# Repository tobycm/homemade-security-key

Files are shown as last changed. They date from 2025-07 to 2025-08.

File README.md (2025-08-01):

# homemade-security-key

DIY a security key! powered by a rp2350 for a pretty good security :D

with a nice 3d printed case and it is also easy to print, this key is hella nice for only 6$ each 🔥

the pcb is still well made tho, considerate thoughts have been put into the usb routing, and power delivery too!

## 3D Render

### PCB

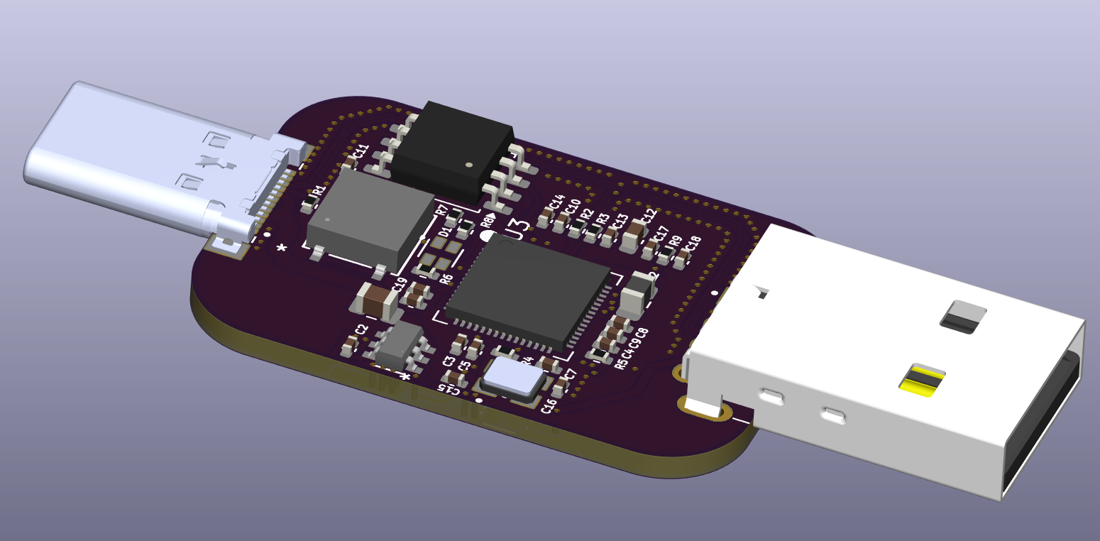
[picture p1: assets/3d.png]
3d render


### Case

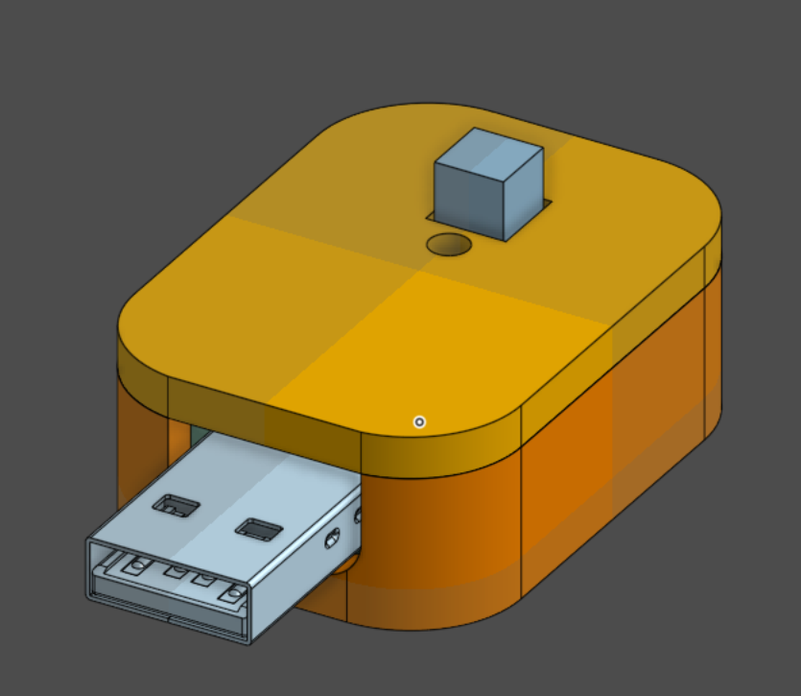
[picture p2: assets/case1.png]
case1


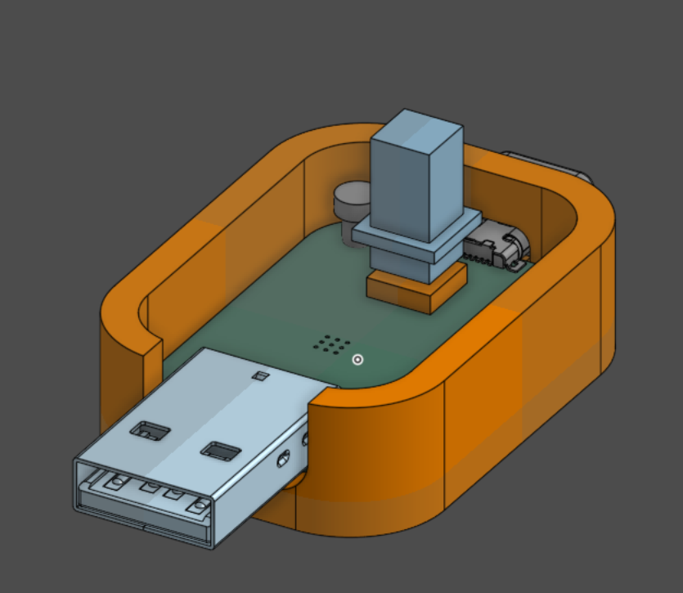
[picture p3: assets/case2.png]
case2


| Type | Qty | Value |
| :--- | :-- | :--- |
| Capacitor | 1 | 10u |
| Capacitor | 10 | 100n |
| Capacitor | 1 | 1u |
| Capacitor | 1 | 22u |
| Capacitor | 4 | 4.7u |
| Capacitor | 2 | 18p |
| LED | 1 | B38G3RGB-10D0003H2U1930 |
| Connector | 1 | UP20-C-F-G-FL-1-P12-TR |
| Connector | 1 | UP2-AH-1-TH |
| Inductor | 1 | 4.7u |
| Inductor | 1 | AOTA-B201610S3R3-101-T |
| Resistor | 1 | 5.1k |
| Resistor | 2 | 27 |
| Resistor | 1 | 1k |
| Resistor | 1 | 10k |
| Resistor | 1 | 147 |
| Resistor | 3 | 33 |
| Button | 1 | PTS526SM15SMTR2 LFS |
| Buck regulator | 1 | AP63203WU-7 |
| Flash | 1 | W25Q16JVSS |
| MCU | 1 | RP2350A-QFN60 |
| Crystal | 1 | ABM8-272-T3 |
| PCB | 1 | |
| Stencil | 1 | |
| Solder paste | 1 | I already have |

---
**Total cost:** $64.78 USD

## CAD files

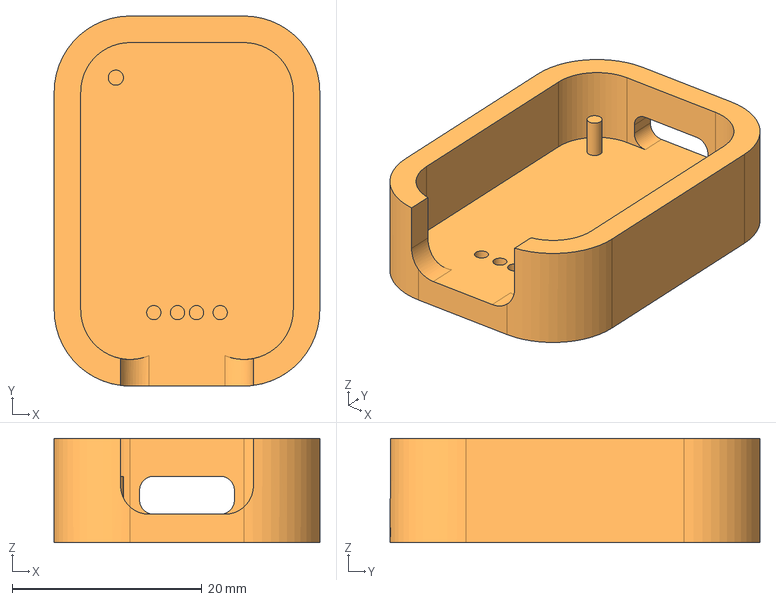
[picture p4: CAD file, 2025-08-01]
3d/main case.step
28.0 x 39.0 x 11.0 mm

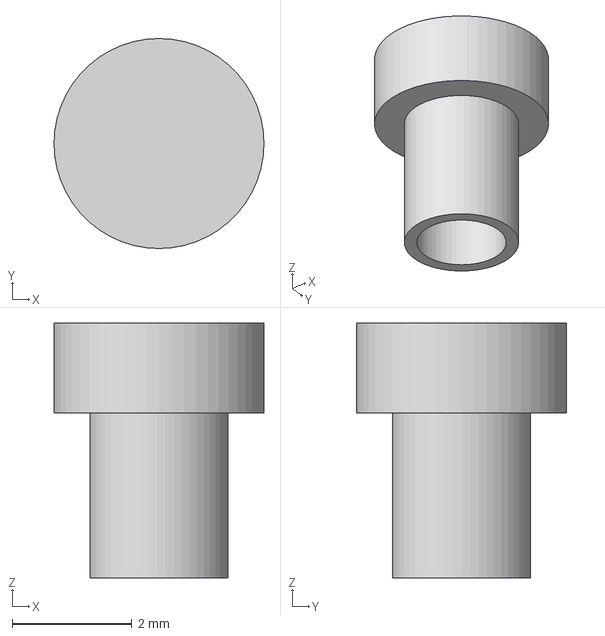
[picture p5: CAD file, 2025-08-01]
3d/tight fit.step
3.50 x 3.50 x 4.25 mm

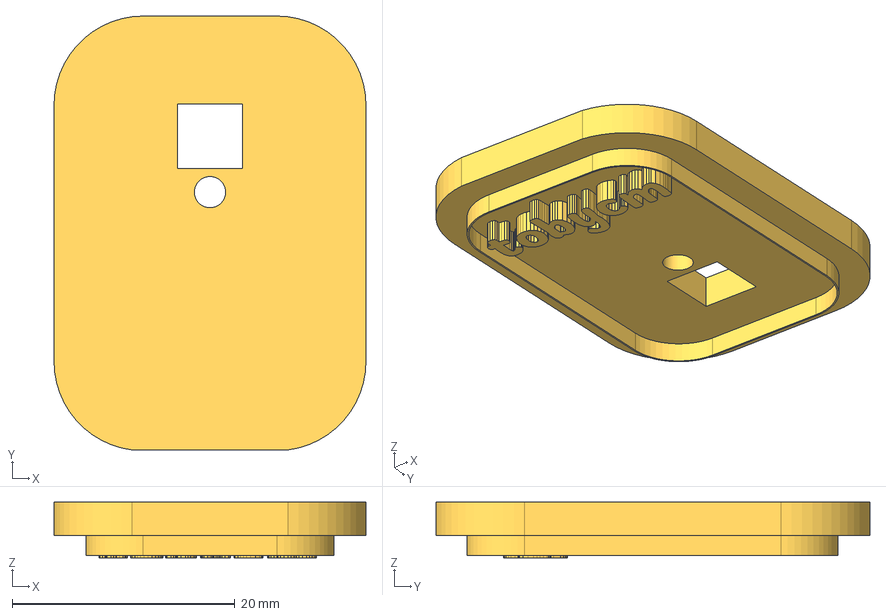
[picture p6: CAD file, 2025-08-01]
3d/top case plate.step
28.0 x 38.9 x 5.00 mm

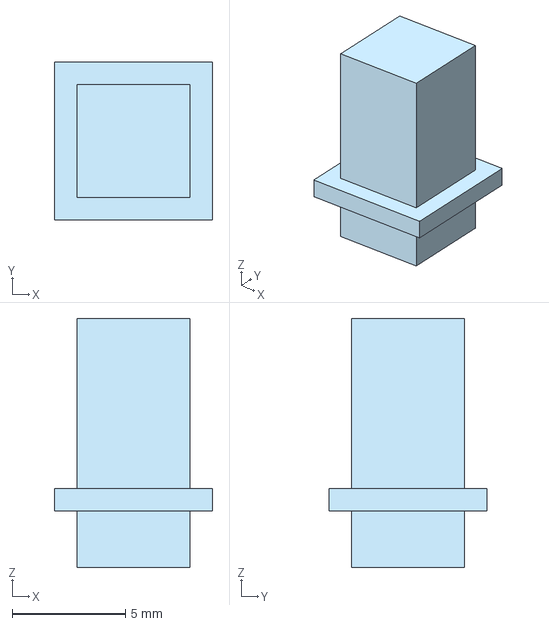
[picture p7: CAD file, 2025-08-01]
3d/button.step
7.00 x 7.00 x 11.0 mm

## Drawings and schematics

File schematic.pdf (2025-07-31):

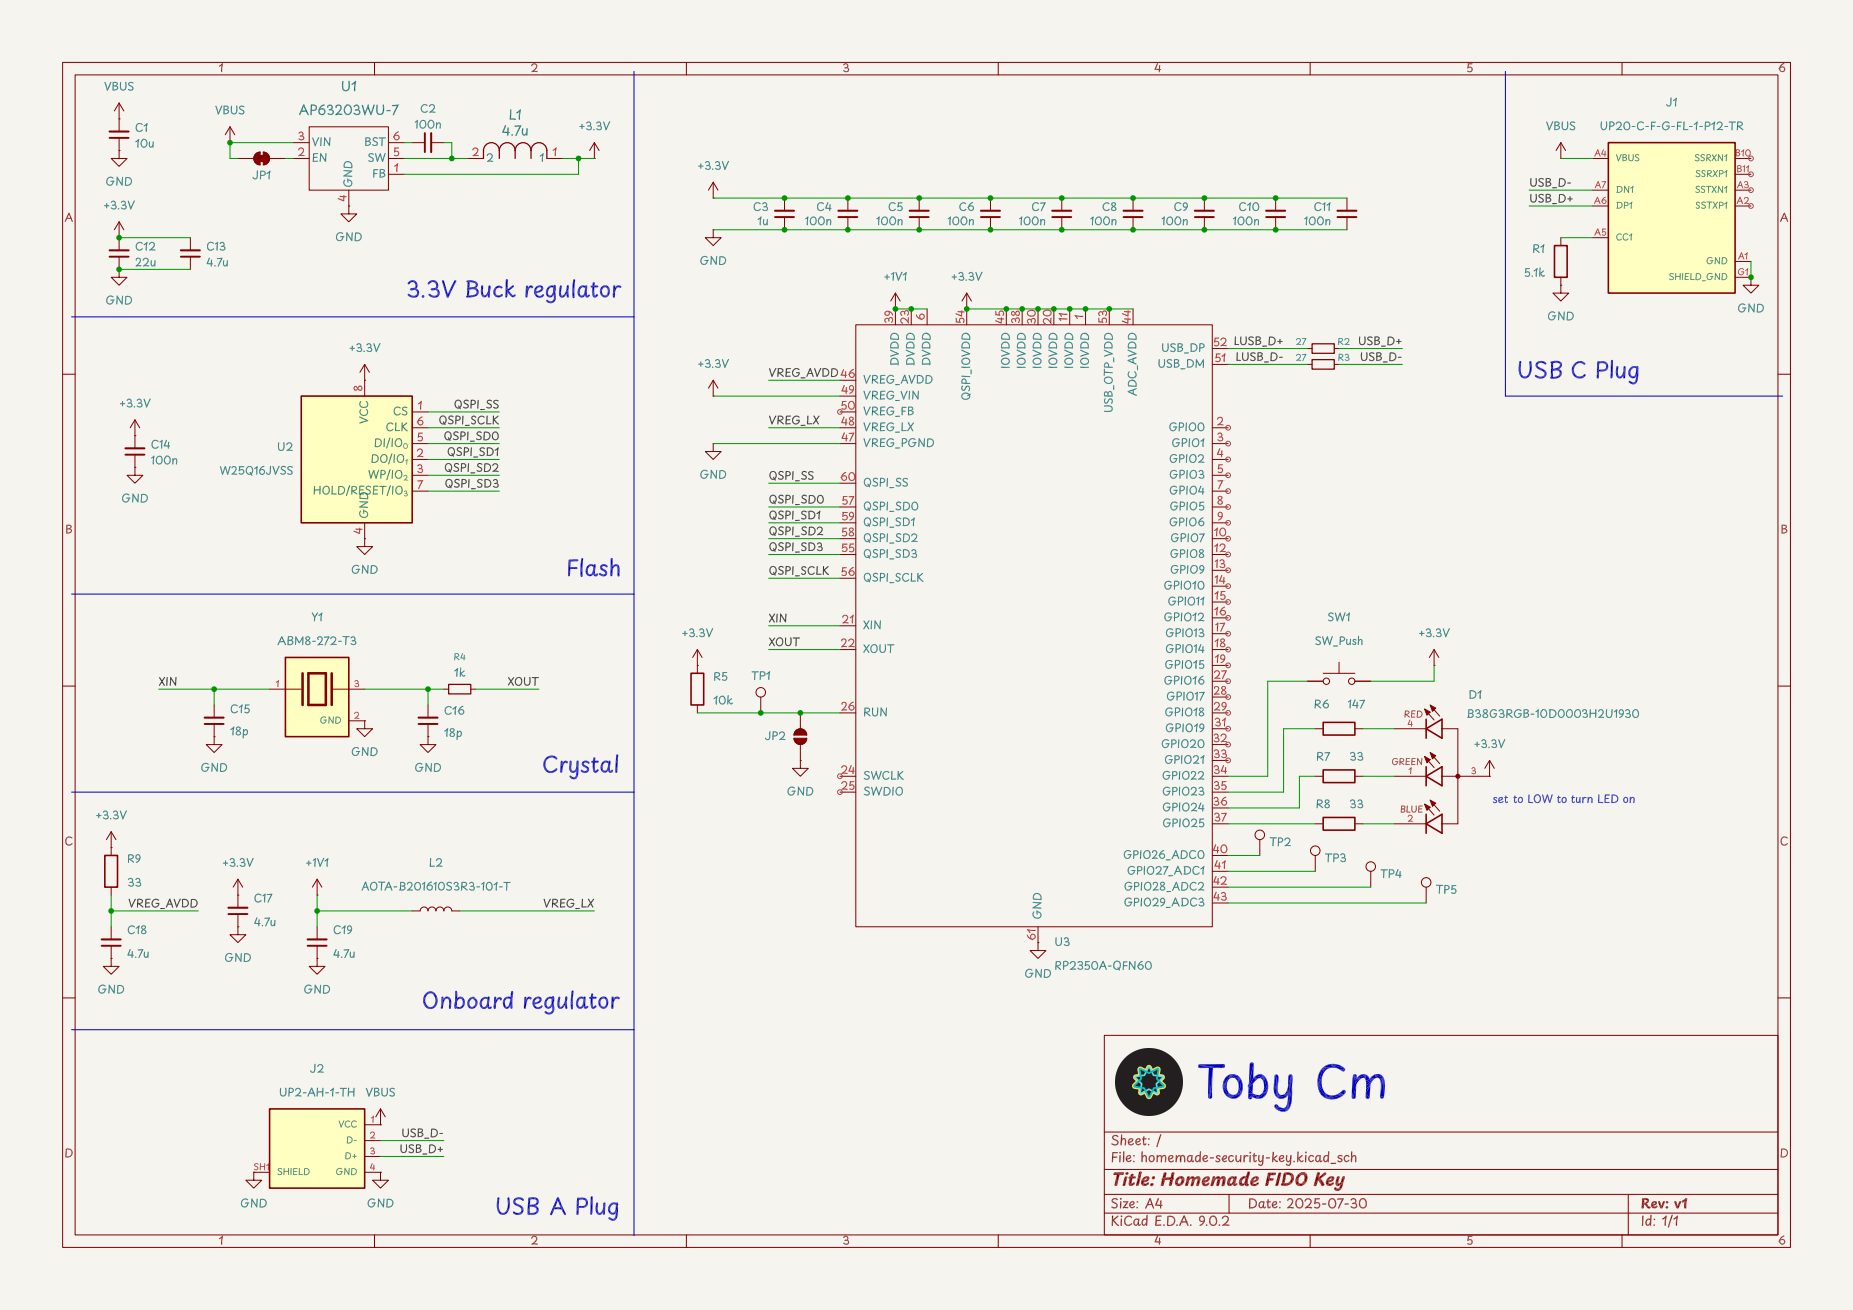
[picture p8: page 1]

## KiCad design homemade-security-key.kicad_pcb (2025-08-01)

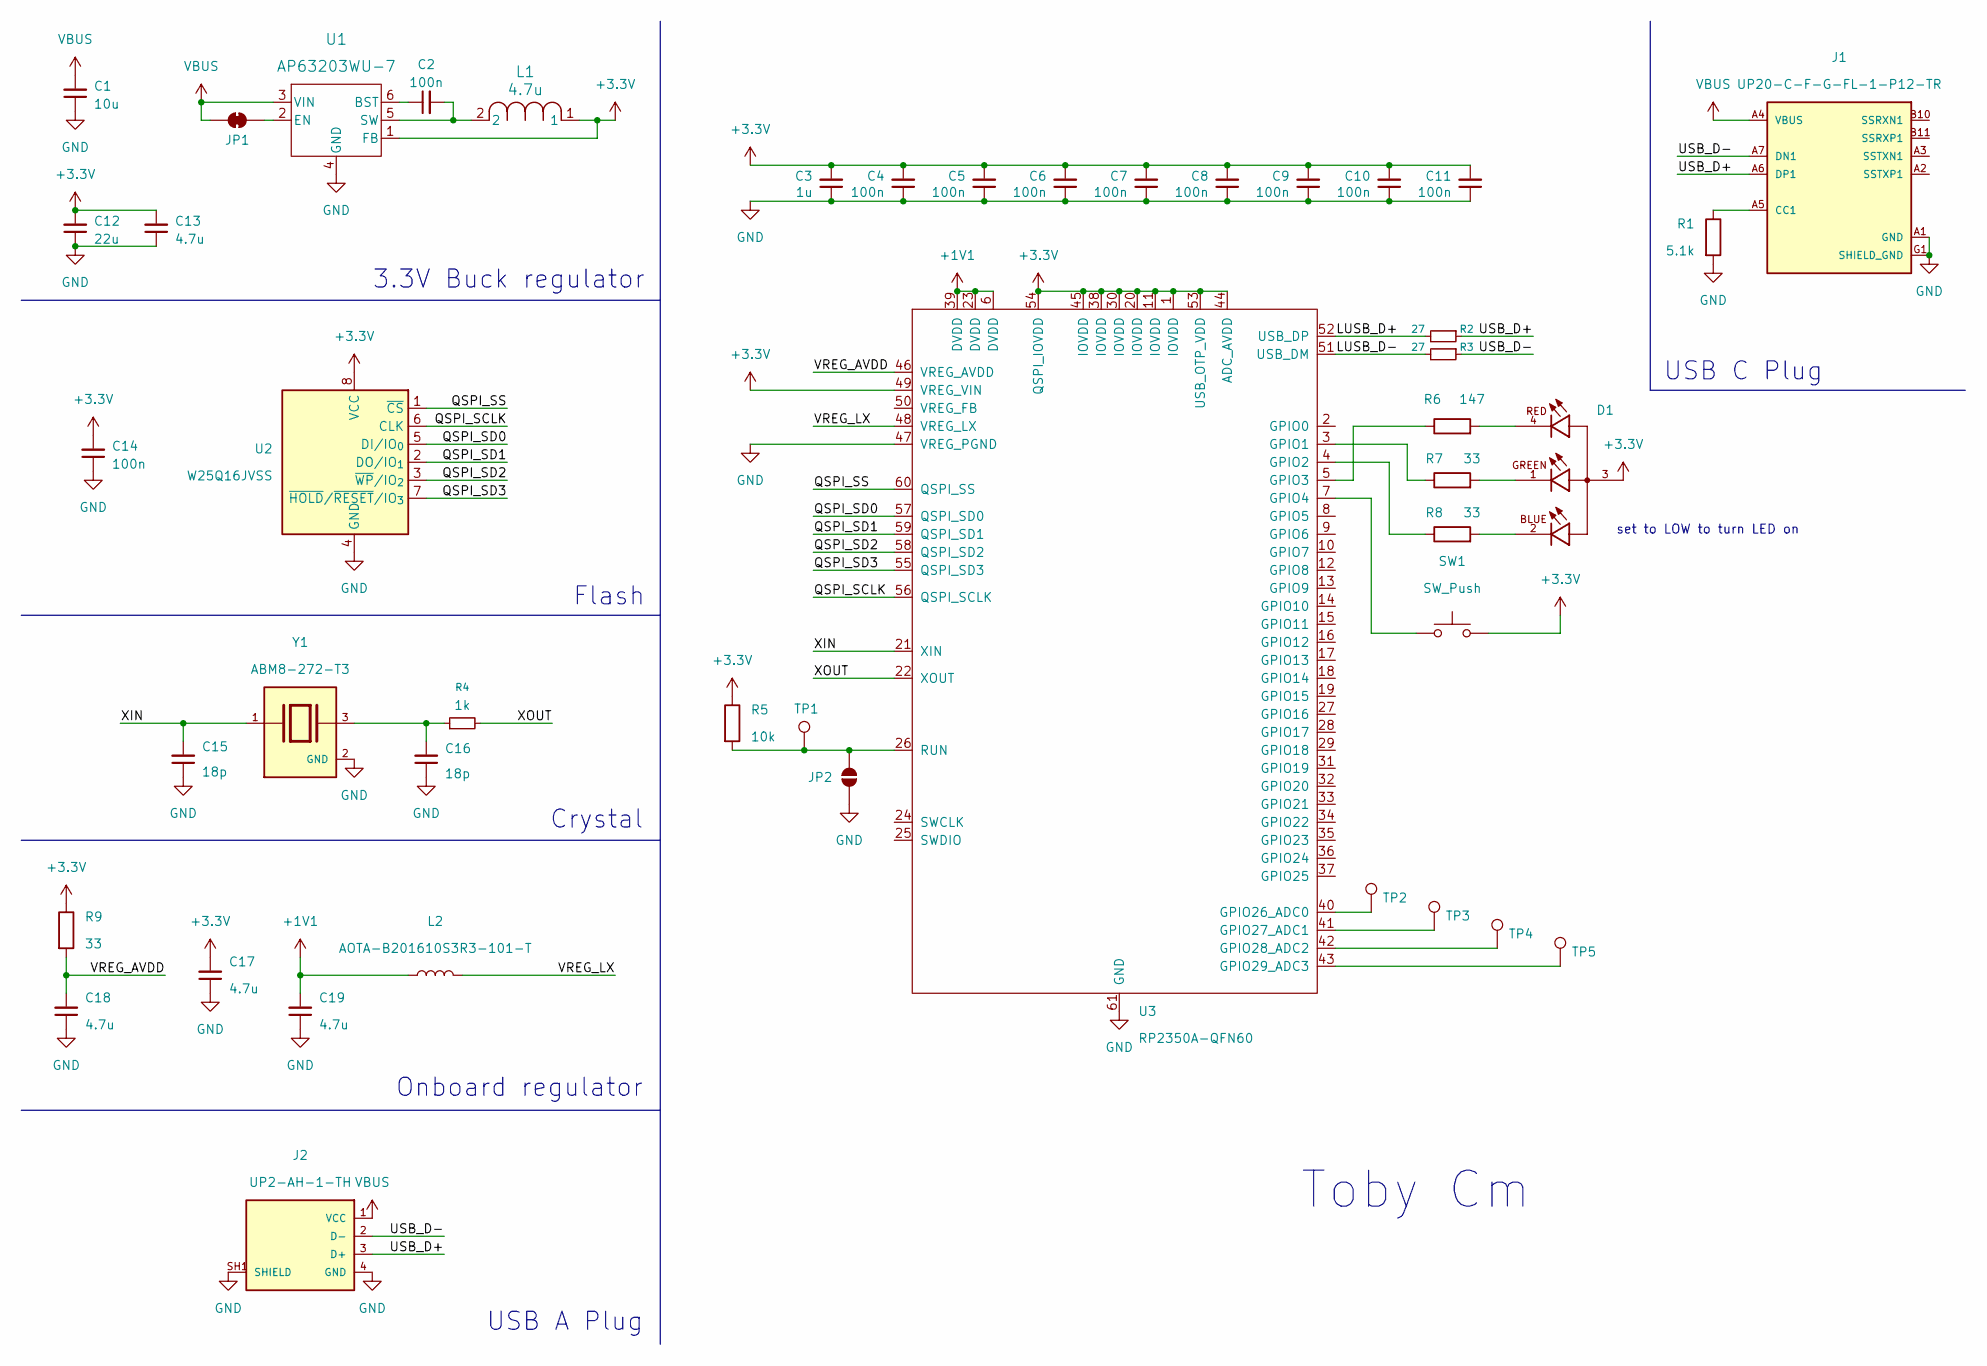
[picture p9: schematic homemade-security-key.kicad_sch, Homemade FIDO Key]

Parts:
C1: 10u; C_0805_2012Metric
C2, C4, C5, C6, C7, C8, C9, C10, C11, C14: 100n; C_0402_1005Metric
C3: 1u; C_0402_1005Metric
C12: 22u; C_0603_1608Metric
C13, C17, C18, C19: 4.7u; C_0402_1005Metric
C15, C16: 18p; C_0402_1005Metric
D1: B38G3RGB-10D0003H2U1930; LED_B38G3RGB-10D0003H2U1930; PARTREV 1.9
J1: UP20-C-F-G-FL-1-P12-TR; SAMESKY_UP20-C-F-G-FL-1-P12-TR; PARTREV 1.0
J2: UP2-AH-1-TH; CUI_UP2-AH-1-TH; PARTREV 1.05
JP1: SolderJumper_2_Bridged; SolderJumper-2_P1.3mm_Bridged_RoundedPad1.0x1.5mm
JP2: SolderJumper_2_Open; SolderJumper-2_P1.3mm_Open_RoundedPad1.0x1.5mm
L1: 4.7u; IND_HPC6045NC_TTA
L2: AOTA-B201610S3R3-101-T; L_0805_2012Metric_Pad1.15x1.40mm_HandSolder
R1: 5.1k; R_0402_1005Metric
R2, R3: 27; R_0402_1005Metric
R4: 1k; R_0402_1005Metric
R5: 10k; R_0402_1005Metric
R6: 147; R_0402_1005Metric
R7, R8, R9: 33; R_0402_1005Metric
SW1: SW_Push; SON4_PTS526 SM15 SMTR2 LFS_CNK
TP1, TP2, TP3, TP4, TP5: TestPoint; TestPoint_Pad_D2.0mm
U1: AP63203WU-7; AP63203WU-7_DIO
U2: W25Q16JVSS; SOIC-8_5.3x5.3mm_P1.27mm
U3: RP2350A-QFN60; RP2350A_QFN-60_EP_7.75x7.75_Pitch0.4mm
Y1: ABM8-272-T3; XTAL_ABM8-272-T3; PARTREV 07-29-20

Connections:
+1V1: C19.2, L2.1, U3.6 (DVDD), U3.23 (DVDD), U3.39 (DVDD)
+3.3V: C3.2, C4.2, C5.2, C6.2, C7.2, C8.2, C9.2, C10.2, C11.2, C12.2, C13.2, C14.2, C17.2, D1.3, L1.1, R5.1, R9.1, SW1.3, SW1.4, U1.1 (FB), U2.8 (VCC), U3.1 (IOVDD), U3.11 (IOVDD), U3.20 (IOVDD), U3.30 (IOVDD), U3.38 (IOVDD), U3.44 (ADC_AVDD), U3.45 (IOVDD), U3.49 (VREG_VIN), U3.53 (USB_OTP_VDD), U3.54 (QSPI_IOVDD)
/LUSB_D+: R2.2, U3.52 (USB_DP)
/LUSB_D-: R3.2, U3.51 (USB_DM)
/QSPI_SCLK: U2.6 (CLK), U3.56 (QSPI_SCLK)
/QSPI_SD0: U2.5 (DI/IO_{0}), U3.57 (QSPI_SD0)
/QSPI_SD1: U2.2 (DO/IO_{1}), U3.59 (QSPI_SD1)
/QSPI_SD2: U2.3 (~WP/IO_{2}), U3.58 (QSPI_SD2)
/QSPI_SD3: U2.7 (~HOLD/~RESET/IO_{3}), U3.55 (QSPI_SD3)
/QSPI_SS: U2.1 (~CS), U3.60 (QSPI_SS)
/USB_D+: J1.A6 (DP1), J2.3 (D+), R2.1
/USB_D-: J1.A7 (DN1), J2.2 (D-), R3.1
/VREG_AVDD: C18.2, R9.2, U3.46 (VREG_AVDD)
/VREG_LX: L2.2, U3.48 (VREG_LX)
/XIN: C15.2, U3.21 (XIN), Y1.1
/XOUT: R4.2, U3.22 (XOUT)
GND: C1.1, C3.1, C4.1, C5.1, C6.1, C7.1, C8.1, C9.1, C10.1, C11.1, C12.1, C13.1, C14.1, C15.1, C16.1, C17.1, C18.1, C19.1, J1.A1 (GND), J1.A12 (GND__1), J1.B12 (GND__2), J1.G1 (SHIELD_GND), J1.G2 (SHIELD_GND__1), J1.G3 (SHIELD_GND__2), J1.G4 (SHIELD_GND__3), J2.4 (GND), J2.SH1 (SHIELD), J2.SH2 (SHIELD__1), JP2.1 (A), R1.2, U1.4 (GND), U2.4 (GND), U3.47 (VREG_PGND), U3.61 (GND), Y1.2 (GND), Y1.4 (GND)
unnamed: C16.2, R4.1, Y1.3
unnamed: D1.1, R7.2
unnamed: D1.2, R8.2
unnamed: D1.4, R6.2
unnamed: J1.A5 (CC1), R1.1
unnamed: JP1.2 (B), U1.2 (EN)
unnamed: JP2.2 (B), R5.2, TP1.1, U3.26 (RUN)
unnamed: C2.1, U1.6 (BST)
unnamed: C2.2, L1.2, U1.5 (SW)
unnamed: R7.1, U3.3 (GPIO1)
unnamed: R8.1, U3.4 (GPIO2)
unnamed: R6.1, U3.5 (GPIO3)
unnamed: SW1.1, SW1.2, U3.7 (GPIO4)
unnamed: TP2.1, U3.40 (GPIO26_ADC0)
unnamed: TP3.1, U3.41 (GPIO27_ADC1)
unnamed: TP4.1, U3.42 (GPIO28_ADC2)
unnamed: TP5.1, U3.43 (GPIO29_ADC3)
VBUS: C1.2, J1.A4 (VBUS), J1.B9 (VBUS__1), J2.1 (VCC), JP1.1 (A), U1.3 (VIN)

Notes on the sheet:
Toby Cm
Flash
Crystal
Onboard regulator
set to LOW to turn LED on
3.3V Buck regulator
USB C Plug
USB A Plug

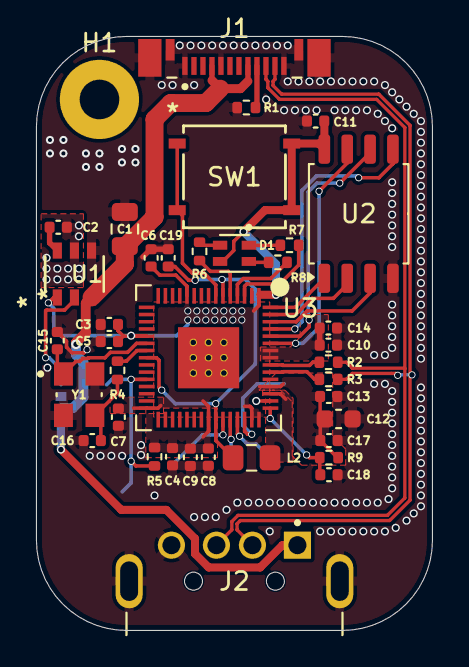
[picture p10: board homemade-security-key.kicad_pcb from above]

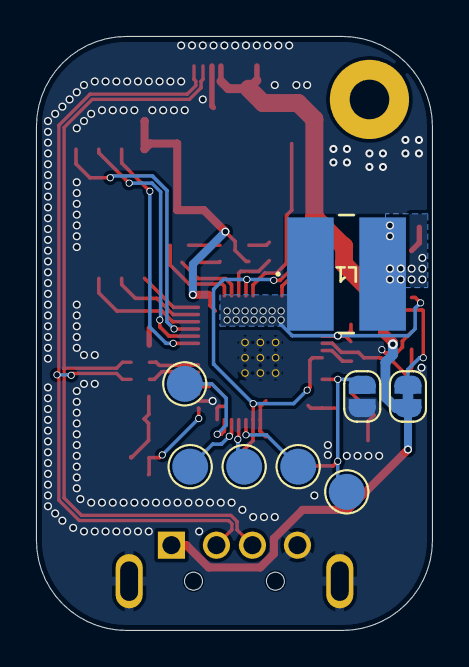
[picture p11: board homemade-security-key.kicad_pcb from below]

Board: 2 copper layers, 22.0 x 33.0 mm, 46 parts (8 on the bottom side), 35 nets.

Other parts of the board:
H1: MountingHole; MountingHole_2.2mm_M2_Pad

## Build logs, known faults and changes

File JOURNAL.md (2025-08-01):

---
author: tobycm
created_at: "2025-07-26"
description: time to DIY your own security key!! powered by the modern rp2350 MCU!
title: homemade security key
---

# Homemade Security Key with RP2350

the S in RP2350 stands for security :)

### Total hours: 21

## Jul 30 | 14:00 - 21:00 | time to wire up the rp2350a

why did i choose the rp2350 you may ask? the rp2040 is designed to support secure environments when Secure Boot is enabled, and optionally, Secure Lock. These features allow a master key encryption key (MKEK) to be stored in a one-time programmable (OTP) memory region, which is inaccessible from outside secure code. This master key is then used to encrypt all private and secret keys on the device, protecting sensitive data from potential flash memory dumps.

even though the rp2350 is harder to wire up than the rp2040, it is worth it for the security features it provides. it also isnt that much harder to wire up too. you only need to add a few more components for the onboard regulator.

[https://datasheets.raspberrypi.com/rp2350/hardware-design-with-rp2350.pdf](https://datasheets.raspberrypi.com/rp2350/hardware-design-with-rp2350.pdf): a great resource for wiring up the rp2350

the rp2350b offers more GPIOs, but the rp2350a is sufficient for this project.

part list made: [https://www.digikey.ca/en/mylists/list/QRE80YFRXG](https://www.digikey.ca/en/mylists/list/QRE80YFRXG)

$38.92 total, not bad!

copying some stuff from my last rp2040 project hehe

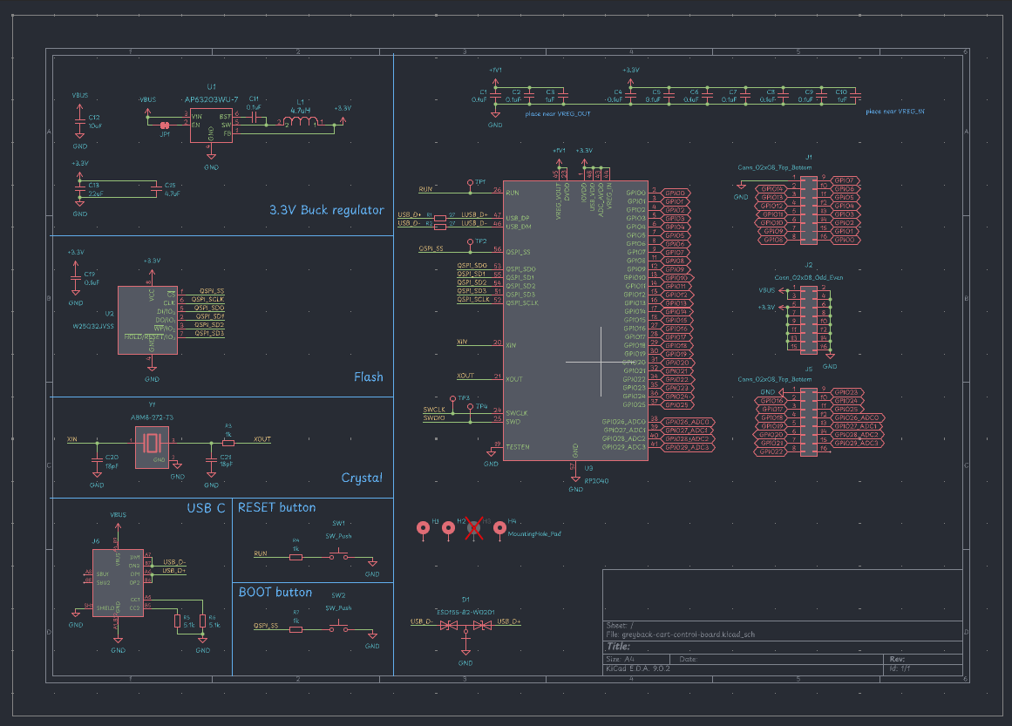
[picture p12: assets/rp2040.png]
last rp2040 project


Schematic is done!!!: [schematic](schematic.pdf)

pcb is done too!!!! gruesome 3 hours of work :pf:

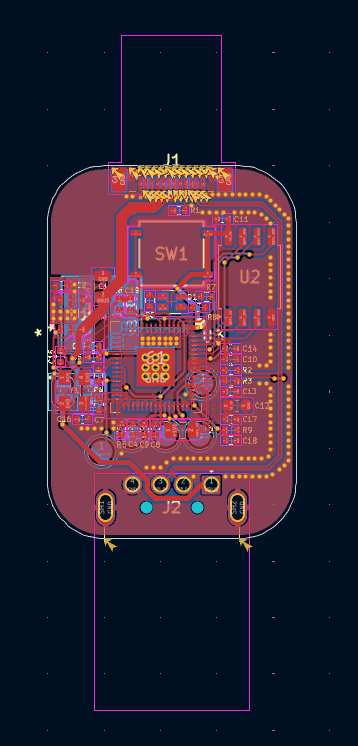
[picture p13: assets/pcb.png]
pcb


3d render

okay i will just need to make a case for it and 3d print it

## Jul 31 | 18:00 -  | last sprint before deadline!!

making 3d case and i realized i dont have anything to mount the board in the case lmao. adding a mounting hole real quick

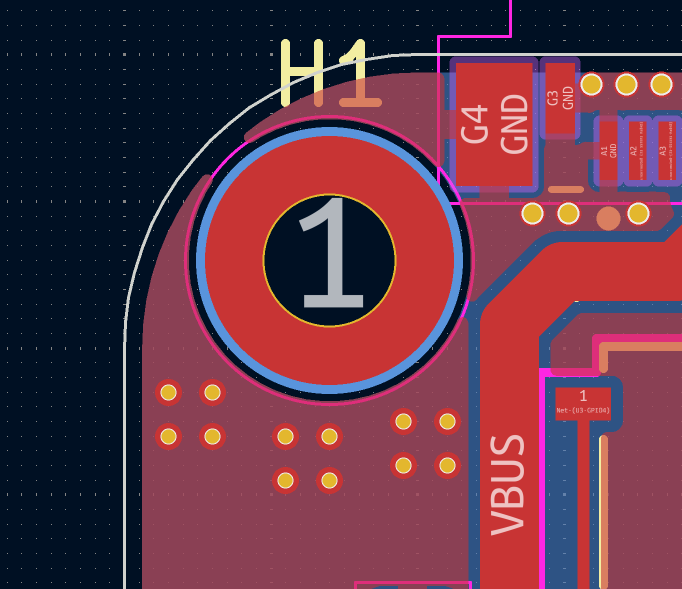
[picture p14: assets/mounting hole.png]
mounting hole


i mean i can just hot glue it 💀

done done!!

case1

case2

the pcb will be secured to the case with a tight fit and maybe some hot glue. the case is designed to be printed without supports, so it should be easy to print.

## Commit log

2025-07-31 pcb done!
    [homemade-security-key.kicad_pcb, homemade-security-key.kicad_sch]
2025-08-01 journal and readme done!!
    [homemade-security-key.kicad_pcb]
2025-08-01 add 3d files
    [button.step, main case.step, tight fit.step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]
2025-08-01 add bom
2025-08-01 final push hehe
    [homemade-security-key.kicad_sch]
2025-08-01 add bom because git ignored it :skull:
    [BOM.csv]
2026-04-25 add gerbers
    [BOM-homemade-security-key.csv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]
